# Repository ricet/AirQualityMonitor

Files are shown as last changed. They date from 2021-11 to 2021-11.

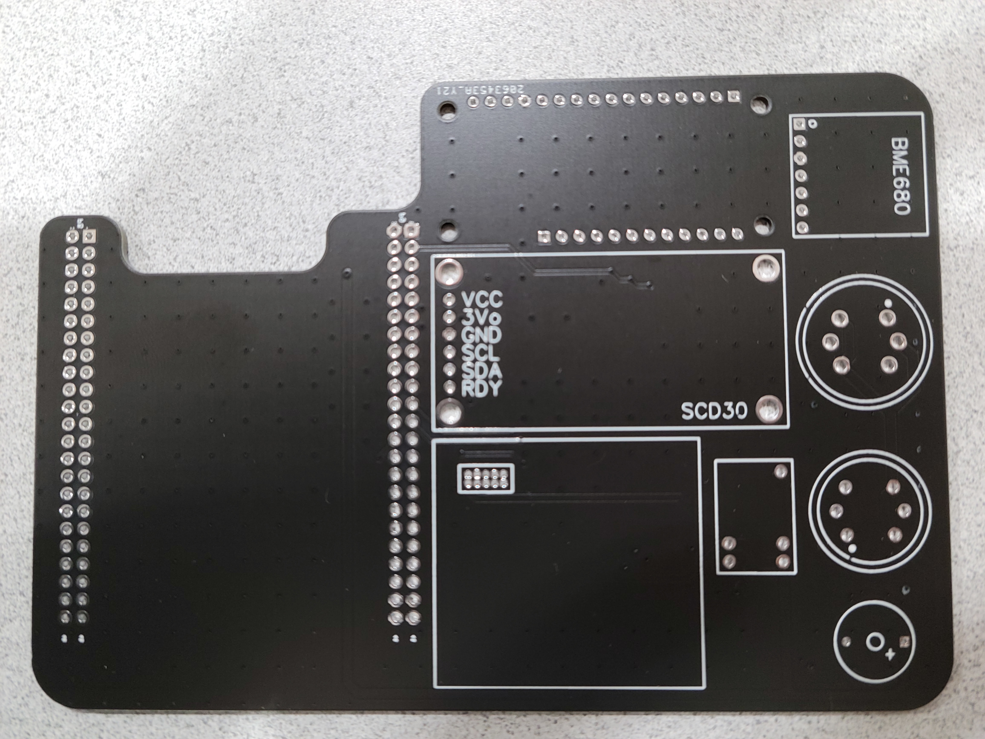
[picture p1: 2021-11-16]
images/Source/PCB_IRL_2.jpg

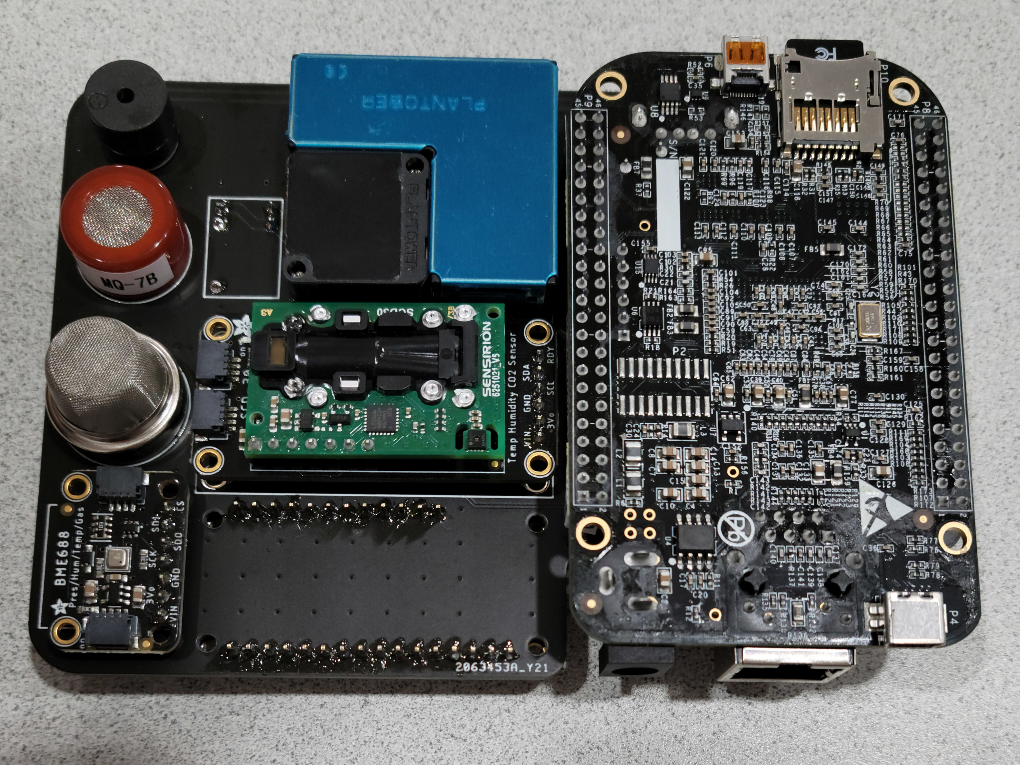
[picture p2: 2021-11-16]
images/Source/Product_2.jpg

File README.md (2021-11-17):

# AirQualityMonitor

With ever-growing issues plaguing air-quality control in houses and industrial complexes alike, the people inhabiting these buildings shouldn't risk their health by trusting in shaky systems.

This project aims to provide a simple and portable solution to help users idenitfy high-risk environment, in terms of the air quality. This product  offers range of sensors that can identify various characteristics of the air around you, such as:
- CO2
- Methane
- Carbone Monoxide
- Particulates
- Temperature
- Humidity
- Pressure

This information is stored locally on the device in an SQLite database. The system runs a Grafana webserver - a graphing utility that organizes the aquired data into a time-series graph (data over time). This can be accessed at the device's IP address.

## Required Hardware
This product is currently not in mass production, as we are merely undergrad students without strong ties with industrial manufacturers. Consequently, we have provided a folder with all the PCB files and the following table with the required components.
| Components | Link to Purchase |
| --- | --- |
| CO2 Sensor | https://www.adafruit.com/product/4867  |
| Carbon Monoxide Sensor | https://www.sparkfun.com/products/9403 |
| Particulate Sensor | https://www.adafruit.com/product/4505  |
| Methane Sensor | https://www.sparkfun.com/products/9404 |
| OLED Display | https://www.adafruit.com/product/4650  |
| Temperature/Humidity Sensor | https://www.adafruit.com/product/5046  |
| Rechargeable Battery | https://www.adafruit.com/category/889  |

Please refer to `/PCB Files` for the PCB schematic and gerber files.

## How to Run
This assumes that you have the required hardware to run. If you do not, this will not work.

The following table outlines the scripts to run, in order to download and install the required libraries and processes.

| Scripts to Run | Description of Script |
| --- | --- |
| libinstall.sh | Installs all the necessary python libraries for interfacing with the sensors |
| grafanainstall.sh | Installs grafana with the sqlite3 plugin and boot-on-startup enabled on Linux. Use this OR grafanainstallv2 |
| grafanainstallv2.sh | Installs grafana with the sqlite3 plugin and boot-on-startup enabled on ARM based machines. Use this OR grafanainstall |
| sqlite3install.sh | Installs sqlite3 |
| setupSystemd.sh | Enables the code to auto-start on bootup |
| removeSystemd.sh | Removes the code from auto-starting on bootup |

To install correctly, run the following:
```
bone$: sudo ./libinstall.sh
bone$: sudo ./grafanainstall.sh
bone$: sudo ./sqlite3install.sh
bone$: sudo ./setupSystemd.sh
```
You may need to run the other provided grafana installer if the first one fails.
```
bone$: sudo ./grafanainstallv2.sh
```

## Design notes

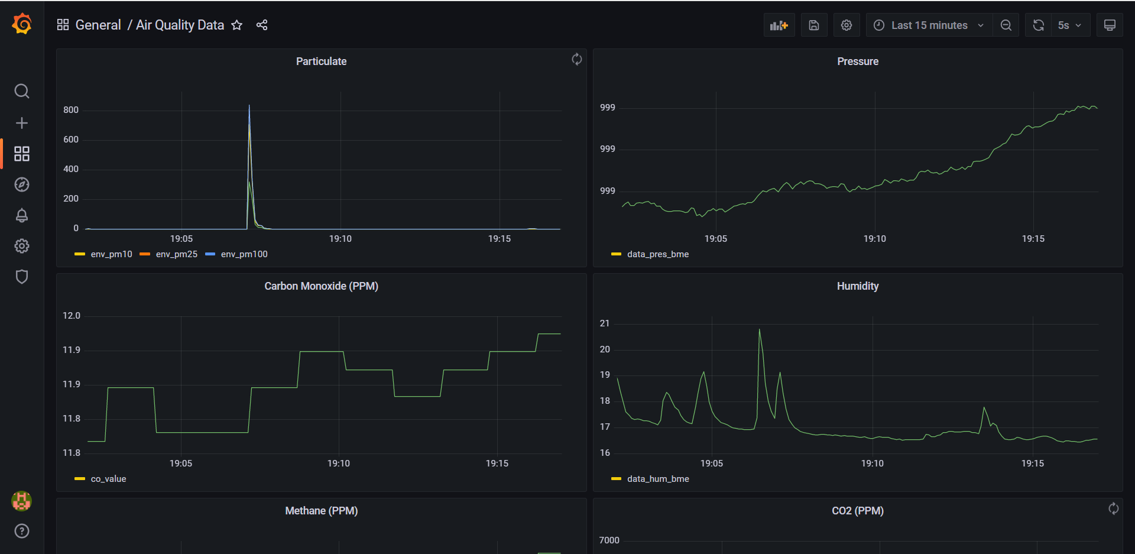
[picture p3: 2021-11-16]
images/Final/AirQuality1.png

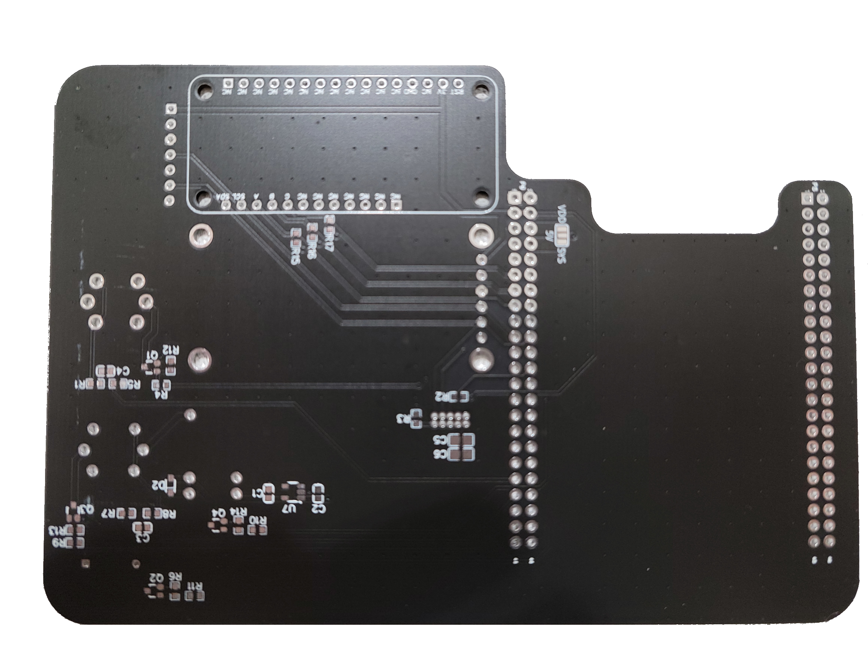
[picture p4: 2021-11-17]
images/Final/PCB_IRL_1.png

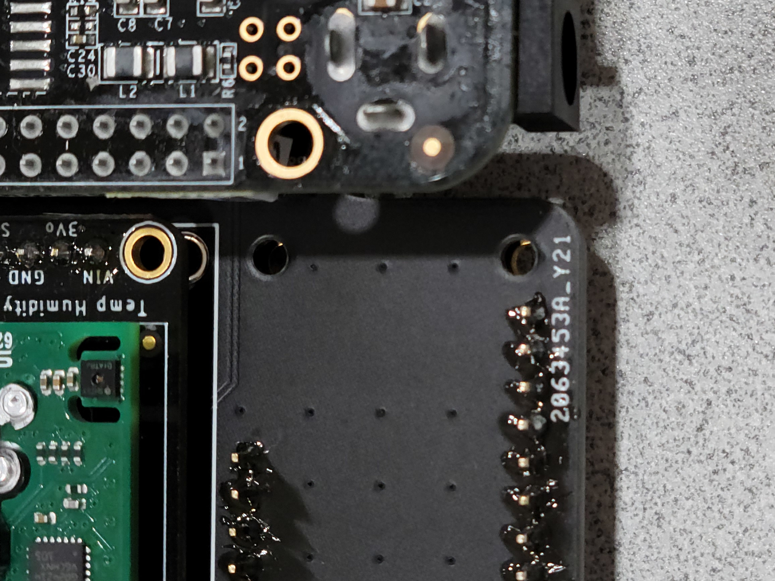
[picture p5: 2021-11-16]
images/Source/Product_1.jpg

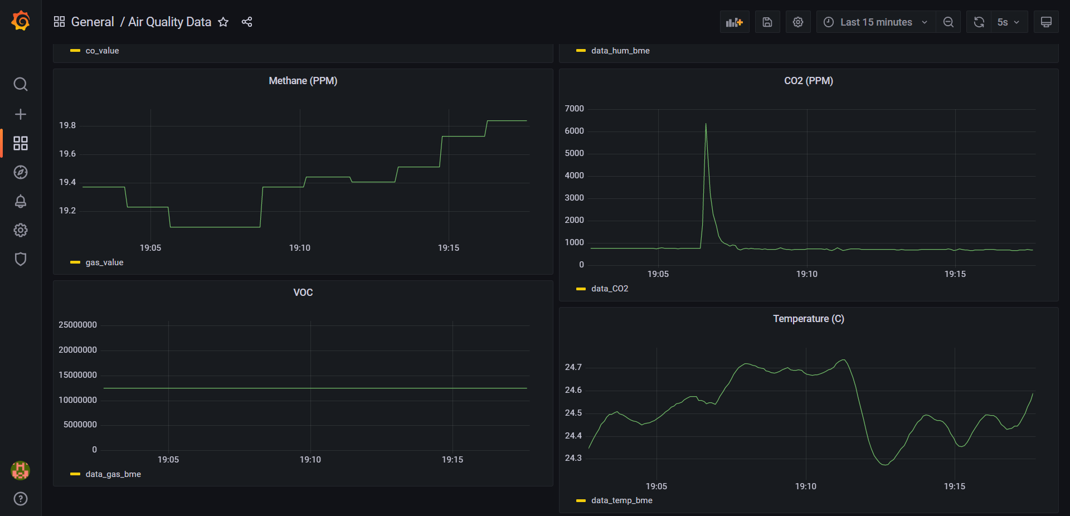
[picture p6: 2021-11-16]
images/Final/AirQuality2.png

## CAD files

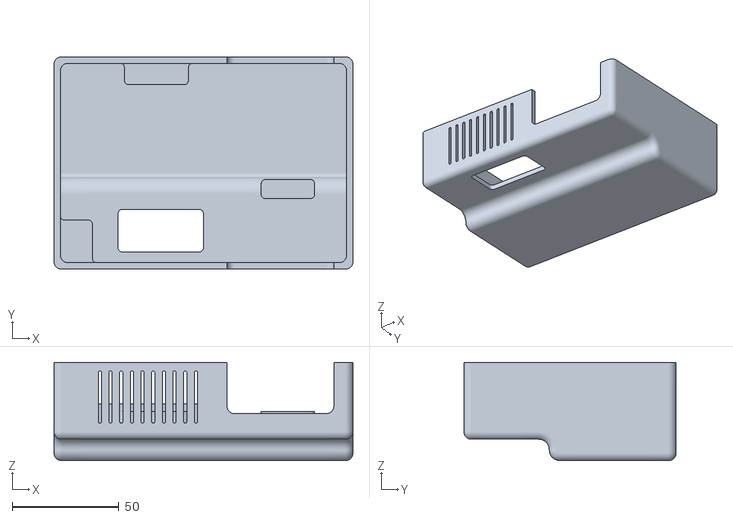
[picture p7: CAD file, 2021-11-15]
enclosure/box.stl
140.1 x 99.4 x 46.0

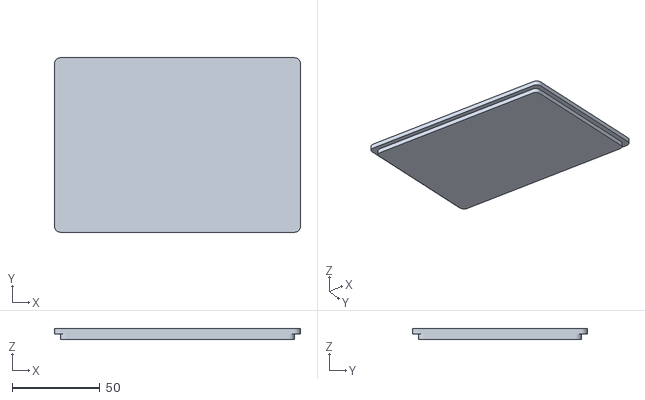
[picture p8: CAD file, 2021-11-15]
enclosure/lid.stl
140.1 x 99.4 x 6.00

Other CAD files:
enclosure/OBJ_PCB_AirQualityMonitor.ipt
enclosure/OldVersions/box.0002.iam
enclosure/OldVersions/box.0007.ipt
enclosure/OldVersions/lid.0003.ipt
enclosure/box.iam
enclosure/box.ipt
enclosure/lid.ipt

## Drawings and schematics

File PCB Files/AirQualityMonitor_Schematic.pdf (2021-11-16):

## SCD30

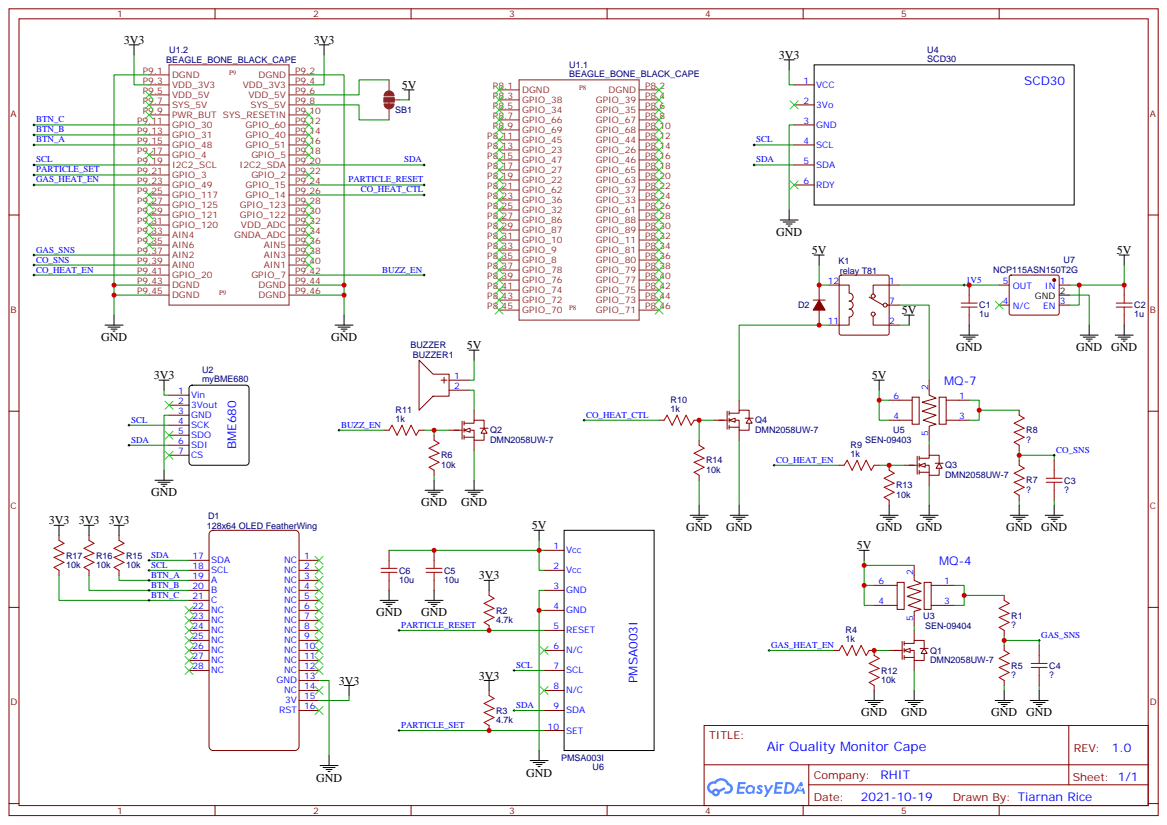
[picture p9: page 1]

Drawn By: Tiarnan Rice

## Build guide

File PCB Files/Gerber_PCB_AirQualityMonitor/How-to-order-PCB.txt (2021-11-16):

How to Order PCB

Please refer to:
https://docs.easyeda.com/en/PCB/Order-PCB

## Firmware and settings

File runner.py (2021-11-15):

#!/usr/bin/env python3
import sqlite3
from random import randrange
from datetime import datetime
import time
import board
import adafruit_scd30
import adafruit_bme680
from adafruit_pm25.i2c import PM25_I2C
import busio
from adafruit_pm25.i2c import PM25_I2C
import Adafruit_BBIO.GPIO as GPIO
import Adafruit_BBIO.ADC as ADC
import signal, sys
import threading
import math


DB_PATH = "/etc/grafana/airQualityData.db"
con = sqlite3.connect(DB_PATH)
cur = con.cursor()

BEEP = "P9_42"
GPIO.setup(BEEP, GPIO.OUT)
GPIO.output(BEEP, 0)

GAS_HEAT_EN = "P9_23"
GPIO.setup(GAS_HEAT_EN, GPIO.OUT)
GPIO.output(GAS_HEAT_EN, 1)

CO_HEAT_EN = "P9_41"
GPIO.setup(CO_HEAT_EN, GPIO.OUT)
GPIO.output(CO_HEAT_EN, 1)

CO_HEAT_CTL = "P9_26"
GPIO.setup(CO_HEAT_CTL, GPIO.OUT)
GPIO.output(CO_HEAT_CTL, 0)

ADC.setup()

def signal_handler(sig, frame):
    GPIO.output(GAS_HEAT_EN, 0)
    GPIO.output(CO_HEAT_EN, 0)
    GPIO.output(CO_HEAT_CTL, 0)
    GPIO.output(BEEP, 0)
    sys.exit(0)
signal.signal(signal.SIGINT, signal_handler)

i2c = board.I2C()
scd = adafruit_scd30.SCD30(i2c)
bme680 = adafruit_bme680.Adafruit_BME680_I2C(i2c, debug=False)
bme680.sea_level_pressure = 1013.25
temperature_offset = -5
i2c2 = busio.I2C(board.SCL, board.SDA, frequency=100000)
reset_pin = None
pm25 = PM25_I2C(i2c2, reset_pin)


def getCO2():
    global data_CO2
    if scd.data_available:
        data_CO2 = scd.CO2


def getBME():
    global data_temp_bme
    global data_gas_bme
    global data_hum_bme
    global data_pres_bme
    global data_alt_bme
    data_temp_bme = bme680.temperature + temperature_offset
    data_gas_bme = bme680.gas
    data_hum_bme = bme680.relative_humidity
    data_pres_bme = bme680.pressure
    data_alt_bme = bme680.altitude


def getParticles():
    try:
        aqdata = pm25.read()
        global env_pm10
        global env_pm25
        global env_pm100
        global particles_03um
        global particles_05um
        global particles_10um
        global particles_25um
        global particles_50um
        global particles_100um
        env_pm10 = aqdata["pm10 env"]
        env_pm25 = aqdata["pm25 env"]
        env_pm100 = aqdata["pm100 env"]
        particles_03um = aqdata["particles 03um"]
        particles_05um = aqdata["particles 05um"]
        particles_10um = aqdata["particles 10um"]
        particles_25um = aqdata["particles 25um"]
        particles_50um = aqdata["particles 50um"]
        particles_100um = aqdata["particles 100um"]
    except RuntimeError:
        print("Unable ro read from sensor, retrying...")

def gasThread():
    while(1):
        global gas_value
        global co_value
        GPIO.output(CO_HEAT_CTL, 0)
        time.sleep(30)
        gas_value = 10.938 * math.exp(1.7742*0.00103271484375*ADC.read_raw("P9_37"))
        co_value = 3.027 * math.exp(1.0698*0.00103271484375*ADC.read_raw("P9_39"))
        print("gas: " + str(gas_value))
        print("co: " + str(co_value))
        time.sleep(1)
        GPIO.output(CO_HEAT_CTL, 0)
        time.sleep(60)

try:
    # Create table
    cur.execute(
        """CREATE TABLE airQualityData
               (date text, data_CO2 real, data_temp_bme real, data_gas_bme real, data_hum_bme real, data_pres_bme real, data_alt_bme real, env_pm10 real, env_pm25 real, env_pm100 real, particles_03um real, particles_05um real, particles_10um real, particles_25um real, particles_50um real, particles_100um real, gas_value real, co_value real)"""
    )

# Insert a row of data
except:
    global data_CO2
    global data_temp_bme
    global data_gas_bme
    global data_hum_bme
    global data_pres_bme
    global data_alt_bme
    global env_pm10
    global env_pm25
    global env_pm100
    global particles_03um
    global particles_05um
    global particles_10um
    global particles_25um
    global particles_50um
    global particles_100um
    global gas_value
    global co_value
    gas_value = -1
    co_value = -1
    gasThread = threading.Thread(target=gasThread)
    gasThread.start()
    for tem in range(1000000):
        now = datetime.now()
        date_time = now.strftime("%Y-%m-%dT%H:%M:%SZ")
        getCO2()
        getBME()
        getParticles()
        cur.execute(
            "INSERT INTO airQualityData VALUES ('"
            + date_time
            + "',"
            + str(data_CO2)
            + ","
            + str(data_temp_bme)
            + ","
            + str(data_gas_bme)
            + ","
            + str(data_hum_bme)
            + ","
            + str(data_pres_bme)
            + ","
            + str(data_alt_bme)
            + ","
            + str(env_pm10)
            + ","
            + str(env_pm25)
            + ","
            + str(env_pm100)
            + ","
            + str(particles_03um)
            + ","
            + str(particles_05um)
            + ","
            + str(particles_10um)
            + ","
            + str(particles_25um)
            + ","
            + str(particles_50um)
            + ","
            + str(particles_100um)
            + ","
            + str(gas_value)
            + ","
            + str(co_value)
            + ")"
        )

        # Save (commit) the changes
        con.commit()
        time.sleep(5)

    gasThread.stop()
    gasThread.join()
    # We can also close the connection if we are done with it.
    # Just be sure any changes have been committed or they will be lost.
    con.close()

    con = sqlite3.connect(DB_PATH)
    cur = con.cursor()

    for row in cur.execute("SELECT * FROM airQualityData ORDER BY date"):
        print(row)

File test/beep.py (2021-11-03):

#!/usr/bin/env python3

import Adafruit_BBIO.GPIO as GPIO
import time

BEEP = "P9_42"
GPIO.setup(BEEP, GPIO.OUT)
GPIO.output(BEEP, 0)

GAS_HEAT_EN = "P9_23"
GPIO.setup(GAS_HEAT_EN, GPIO.OUT)
GPIO.output(GAS_HEAT_EN, 0)

CO_HEAT_EN = "P9_41"
GPIO.setup(CO_HEAT_EN, GPIO.OUT)
GPIO.output(CO_HEAT_EN, 0)

CO_HEAT_CTL = "P9_26"
GPIO.setup(CO_HEAT_CTL, GPIO.OUT)
GPIO.output(CO_HEAT_CTL, 0)

BTN_C = "P9_15"
GPIO.setup(BTN_C, GPIO.IN)

USR3 = "USR3"
GPIO.setup(USR3, GPIO.OUT)
GPIO.output(USR3, 0)

while True:
    if GPIO.input(BTN_C):
        GPIO.output(BEEP, 0)
    else:
        GPIO.output(BEEP, 1)

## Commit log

2021-10-13 added circuitpython lib install script
2021-11-03 particle sensor test
2021-11-03 screen buttons work
2021-11-15 Added Gas and CO2 sensing, threading
2021-11-15 made enclosure
    [OBJ_PCB_AirQualityMonitor.ipt, box.0002.iam, box.0007.ipt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]
2021-11-15 Removed Gas, fixed table printing
    [runner.py]
2021-11-15 added gas back, disabled relay switching
2021-11-15 relay no clicky
2021-11-16 added pcb files
    [Gerber_BoardOutline.GKO, Gerber_BottomLayer.GBL, Gerber_BottomSilkLayer.GBO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]
